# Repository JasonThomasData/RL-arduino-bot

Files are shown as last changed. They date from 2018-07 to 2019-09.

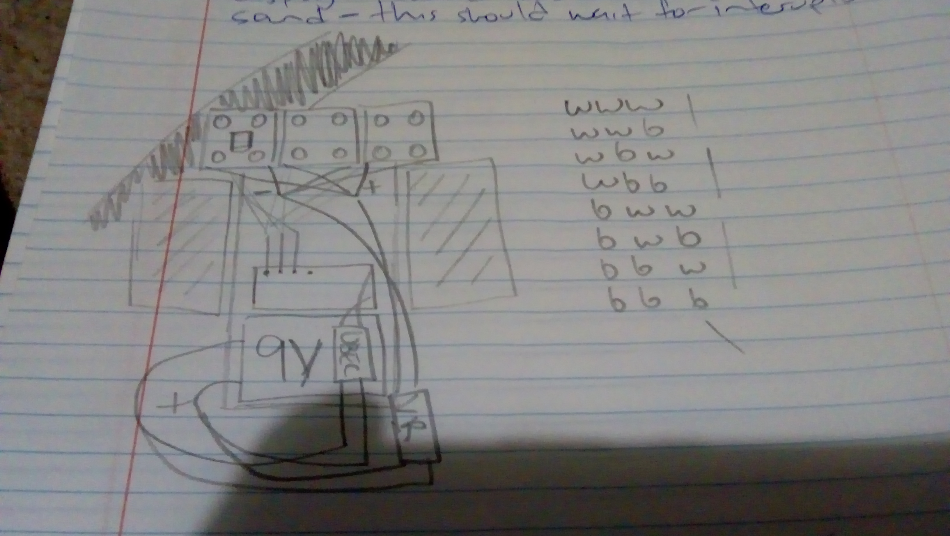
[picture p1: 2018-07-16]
pics/idea1.jpg

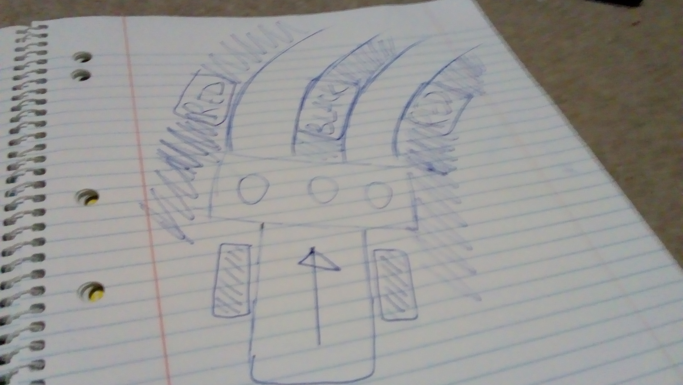
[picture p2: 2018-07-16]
pics/idea2.jpg

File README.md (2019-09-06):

### Requirements

You should download the Arduino IDE to compile the src to your board.

This project uses an Arduino Nano ATMega168 board, or clone. Much of the work on this project was completed using a Mac computer, and if you're using a clone, you will need to [download drivers](https://github.com/adrianmihalko/ch340g-ch34g-ch34x-mac-os-x-driver).

If using a Debian box of some kind, don't use apt to install the Arduino IDE, as [this](https://playground.arduino.cc/Linux/Debian) site warns. Download the binary from their site.

The LinkedList project is in the Sketch, because it is not standard and this is more reliable than Arduino package manager (not sure if it is or not). 

### Tests

```
g++ -std=c++14 tests.cpp -o tests && ./tests
```

### Designs

These parts in `3d_designs/reused_parts/` were incorporated from other projects:

    main_wheel.stl -> https://github.com/davidhrbaty/ArduBot
    small_wheel.stl -> https://github.com/davidhrbaty/ArduBot
    small_wheel_holder.stl -> https://github.com/davidhrbaty/ArduBot
    SG90-A5.stl -> https://www.thingiverse.com/thing:2282898

### Docs

There are a bunch of ideas I drew down in pics/

The control flow diagram was created [here](https://www.draw.io/) and the .xml file is what that app takes for upload. 

### Paths

The paths for the robot to move along are in pics/paths/

These are roughly sized to be printed on A4, but you might need to scale it up slightly.

### Reading

Naming things is hard, so I've reused common names for components by reading [this](http://www-anw.cs.umass.edu/rlr/terms.html).

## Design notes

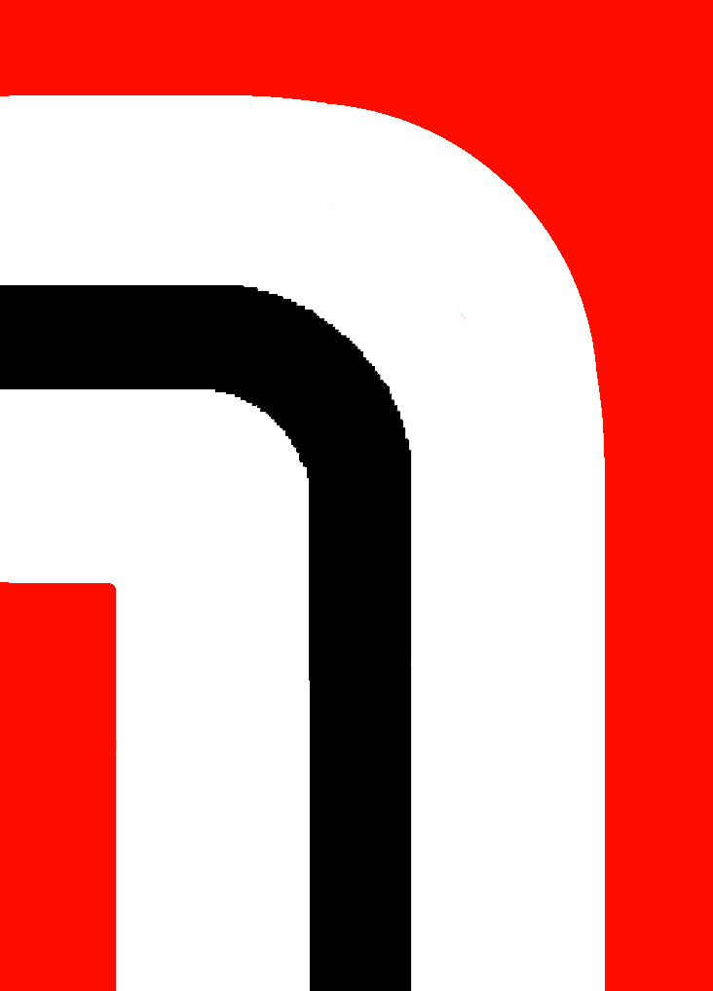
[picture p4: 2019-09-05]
pics/path/turn01.png

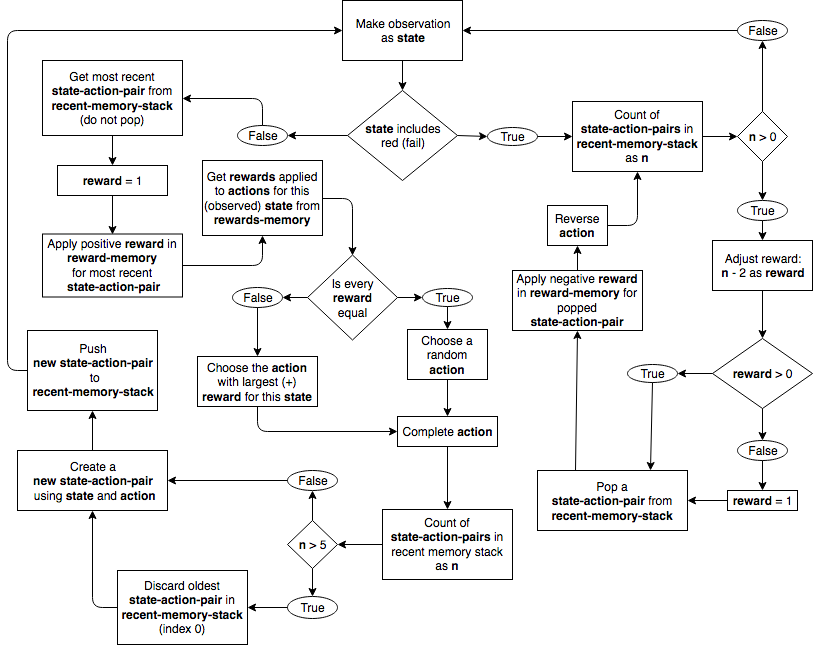
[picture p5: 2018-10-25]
pics/ControlFlow_RL-learning-bot.png

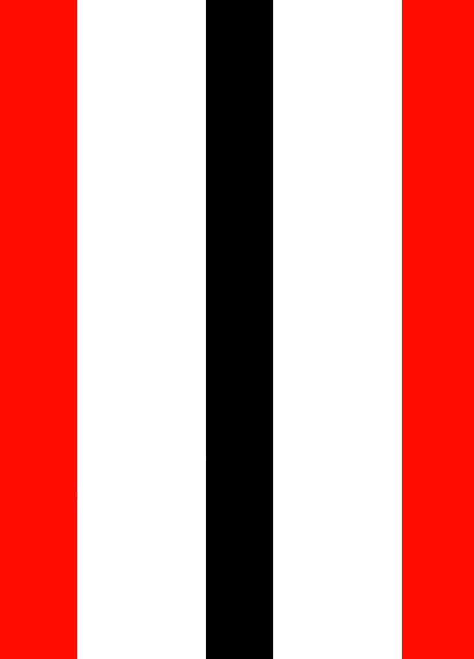
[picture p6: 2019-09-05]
pics/path/straight.png

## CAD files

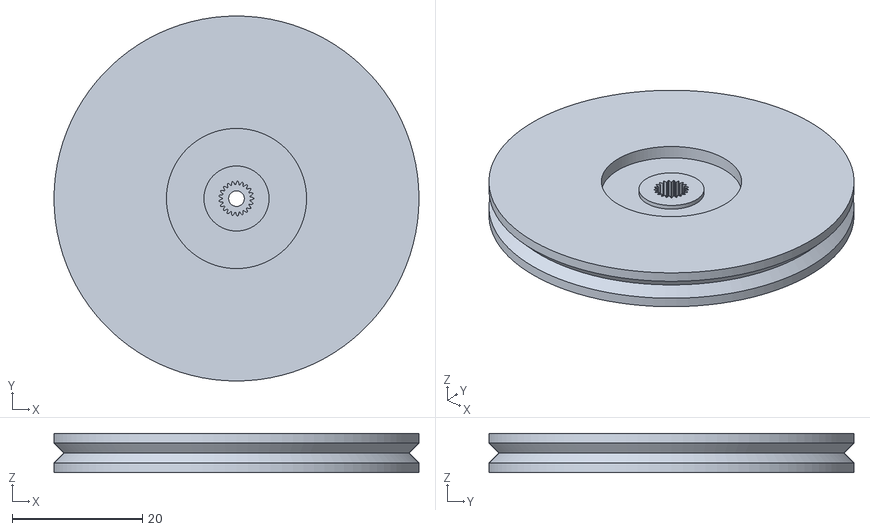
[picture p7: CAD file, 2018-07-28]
3d_designs/main_wheel/main_wheel_with_horn.stl
56.0 x 56.0 x 6.00

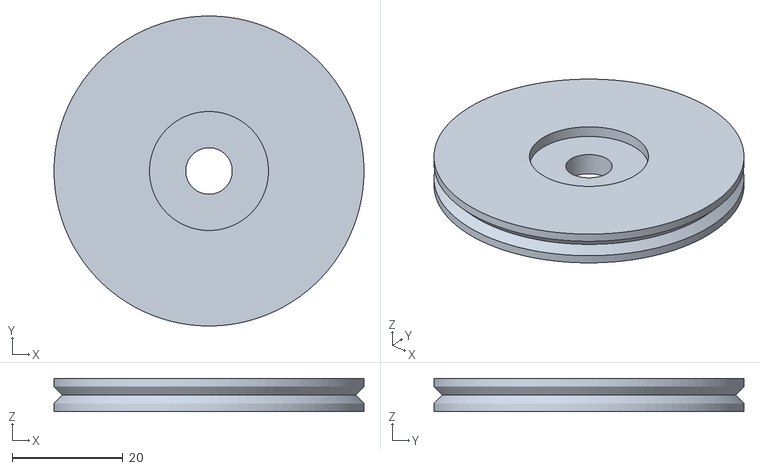
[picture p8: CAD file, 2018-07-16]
3d_designs/reused_parts/main_wheel.stl
56.0 x 56.0 x 6.00

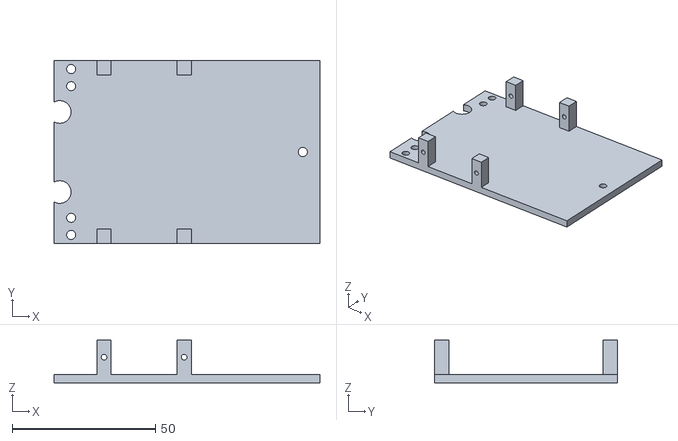
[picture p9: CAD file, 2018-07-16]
3d_designs/chassis/chassis.stl
93.0 x 64.0 x 15.0

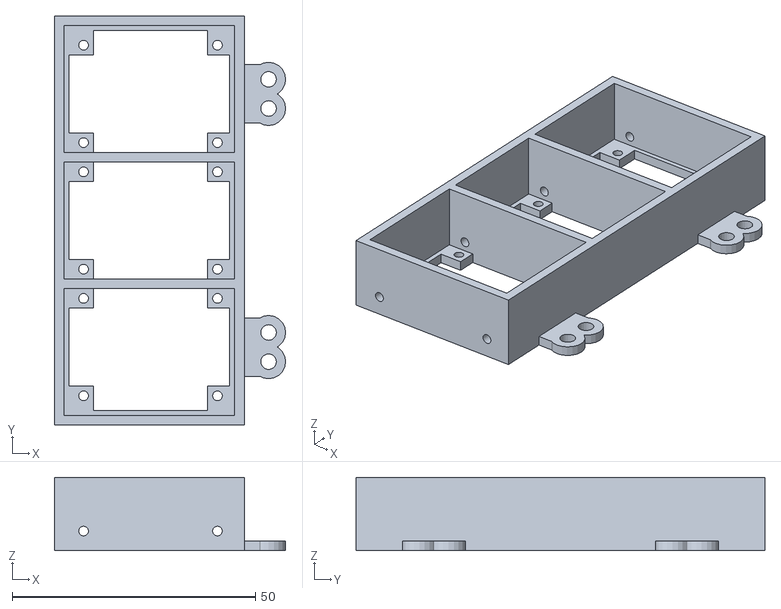
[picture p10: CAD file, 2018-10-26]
3d_designs/sensors/sensors.stl
47.5 x 84.0 x 15.0

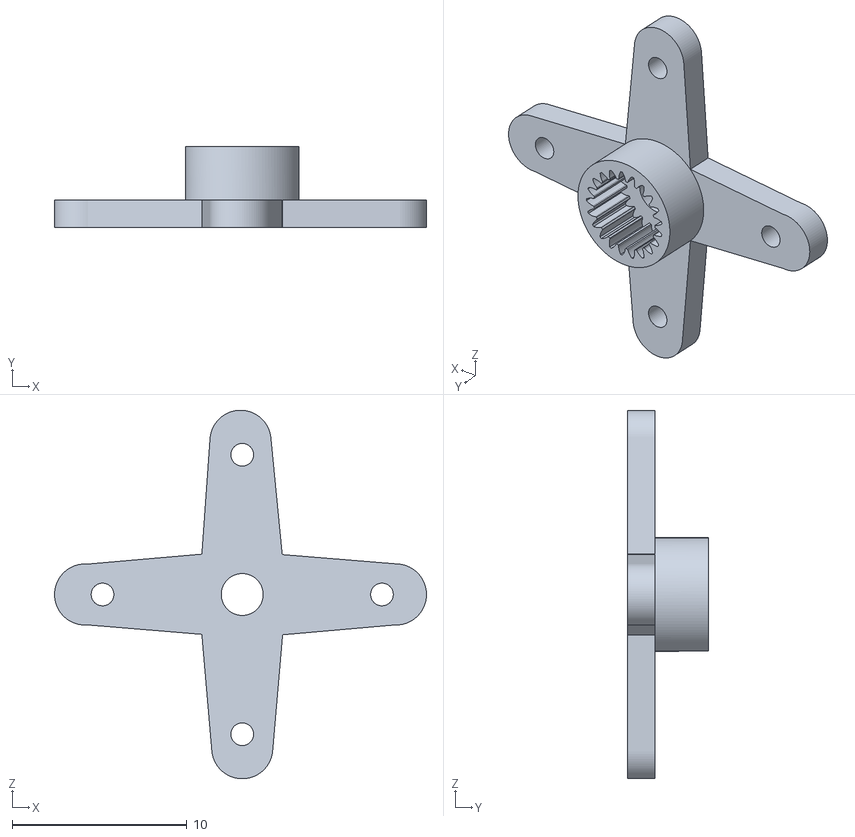
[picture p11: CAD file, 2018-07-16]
3d_designs/reused_parts/SG90-A5.stl
21.3 x 4.66 x 21.1

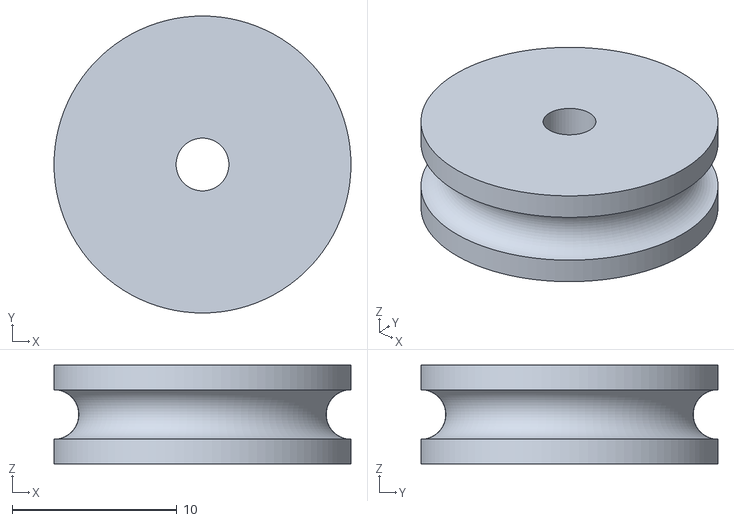
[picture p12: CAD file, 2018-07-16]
3d_designs/reused_parts/small_wheel.stl
18.0 x 18.0 x 6.00

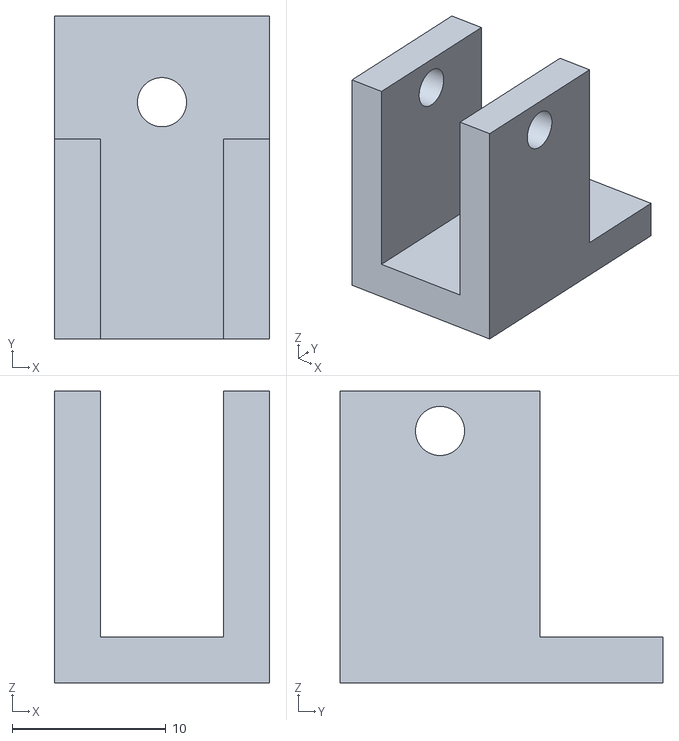
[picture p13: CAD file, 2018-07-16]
3d_designs/reused_parts/small_wheel_holder.stl
14.0 x 21.0 x 19.0

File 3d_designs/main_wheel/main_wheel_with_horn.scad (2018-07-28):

translate([-0.1,10.63,-0.67])
    rotate([90,0,0])
        import("../reused_parts/SG90-A5.stl");

import("../reused_parts/main_wheel.stl");

module wheelHornJoin()
    linear_extrude(height=4.66)
        difference()
        {
            circle(r=5, $fn=50);
            circle(r=3, $fn=20);
        }
 
translate([0,0,-3])
    wheelHornJoin();

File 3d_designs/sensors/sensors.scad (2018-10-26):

use <../common.scad>;

module sensor_holder_block()
    linear_extrude(height=2)
    {
        square([5,5]);
    }
             
module sensor_holder_corner_with_hole(x_offset, y_offset)
    difference()
    {
        sensor_holder_block();
        translate([x_offset,y_offset,0])
            screw_hole(1, 2);
     }

module one_sensor_holder_all_corners()
{
    sensor_holder_corner_with_hole(3, 3); 
    translate([0,21,0])
        sensor_holder_corner_with_hole(3, 2);
    translate([28.5,0,0])
        sensor_holder_corner_with_hole(2, 3);
    translate([28.5,21,0])
        sensor_holder_corner_with_hole(2, 2);
}

module all_sensor_holders()
{
    one_sensor_holder_all_corners();
    translate([0,26,0])
        one_sensor_holder_all_corners();
    translate([0,52,0])
        one_sensor_holder_all_corners();
}

module sensors_mount_outer_brace()
    linear_extrude(height=2)
    {
        square([3,84]);
        translate([36,0,0])
            square([3,84]);
        translate([3,0,0])
            square([33.5,3]);
        translate([3,81,0])
            square([33.5,3]);
    }

module sensors_mount()
{
    sensors_mount_outer_brace();
    translate([3,3,0])
        all_sensor_holders();
}

module sensor_wall(length)
    linear_extrude(height = 15)
    {
        square([length, 2]);
    }

module short_walls()
{
    translate([2,0,0])
        sensor_wall(35);
    translate([2,28,0])
        sensor_wall(35);
    translate([2,54,0])
        sensor_wall(35);
    translate([2,82,0])
        sensor_wall(35);
}

module short_wall_holes()
{
    rotate([-90,0,0])
        translate([6, -4, 0])
            screw_hole(1, 84);
    rotate([-90,0,0])
        translate([33.5, -4, 0])
            screw_hole(1, 84);
}

module long_walls()
{
      translate([2,0,0])
        rotate([0,0,90])
            sensor_wall(84);
    translate([39,0,0])
        rotate([0,0,90])
            sensor_wall(84);
}

module chassis_connector_block()
    linear_extrude(height = 2)
    {
        circle(r=3.5, $fn = 20);
        translate([-5,-3,0])
            square([4, 6]);
    }

module chassis_connector()
    difference()
    {
        chassis_connector_block();
        screw_hole(1.6,2);
    }

module chassis_connectors()
{
    translate([44,10,0])
        chassis_connector();
    translate([44,16,0])
        chassis_connector();
    translate([44,62,0])
        chassis_connector();
    translate([44,68,0])
        chassis_connector();
}

sensors_mount();
difference()
{
    short_walls();
    short_wall_holes();
}
long_walls();
translate([0,3,0])
    chassis_connectors();

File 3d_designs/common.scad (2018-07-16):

module screw_hole(radius, h)
    linear_extrude(height=h)
    {
        circle(r=radius, $fn = 20);
    }

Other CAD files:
3d_designs/chassis/chassis.scad

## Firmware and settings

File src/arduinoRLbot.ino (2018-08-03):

#include <LinkedList.h> // Sketch -> Include Library -> Manage Libraries -> Linked List

/*
 * In this reinforcement learning scenario, the software agent will: 
 *    a) make an observation of the environment state, or of the robot's state in the environment
 *    b) if that state is a fail, and if it is, pop back through list of state-action pairs and give negative rewards. Go back to a)
 *    c) else, give a positive reward for the last state-action pair in list
 *    d) check to see which action has the best reward for the observed state previously
 *    e) complete that action
 *    f) add the state-action pair to the list
 *    REPEAT
 * 
 * It would be preferable to use a HashMap, but, the limitations of an Arduino mean using a fixed length array is more achieveable. However, this means extra care must be paid to naming things, so noone gets confused.
 * Also it would be great to write a minimal unit test suite.
 * 
 * To mitigate against the robot just learning to go backwards and forwards, the robot should detect if it moves a total of zero revs in 10 turns, if so, negative rewards for recorded moves
 * Alternatively, you might use a button to give it a negative reward. 
 */

struct RewardsForActionsAfterObservingAState
{
    int ff; //forward forward
    int fb;
    int bf;
    int bb; //backward backward
};

//Including a hashmap type is too expensive, so this will have to do
//Not sure if a linear search will be performance issue
struct MemoryOfRewardsForStateActionPairs
{
    String key[8];
    RewardsForActionsAfterObservingAState value[8];
};

struct State
{
    char sensorLeft;
    char sensorMiddle;
    char sensorRight;
    char memoryKey[3];
};

struct Action
{
    int leftWheelDirection;
    int rightWheelDirection;
};

struct StateActionPair
{
    State state;
    Action action;
};

struct Sensor
{
    int s0Pin;
    int s1Pin;
    int s2Pin;
    int s3Pin;
    int outputPin;
};

struct ServoInstructions
{
    int signalPin;
    int signalToSet;
};


MemoryOfRewardsForStateActionPairs memoryOfRewardsForStateActionPairs = {
    { "www", "wwb", "wbw", "wbb", "bww", "bwb", "bbw", "bbb" },
    { { 0, 0, 0, 0 }, { 0, 0, 0, 0 }, { 0, 0, 0, 0 }, { 0, 0, 0, 0 }, { 0, 0, 0, 0 }, { 0, 0, 0, 0 }, { 0, 0, 0, 0 }, { 0, 0, 0, 0 } }
};

LinkedList<StateActionPair> mostRecentStateActionPairs = LinkedList<StateActionPair>();

Sensor sensorLeft;
Sensor sensorMiddle;
Sensor sensorRight;

void ConfigureSensor(Sensor *sensor)
{
    pinMode(sensor->s0Pin, OUTPUT);
    pinMode(sensor->s1Pin, OUTPUT);
    pinMode(sensor->s2Pin, OUTPUT);
    pinMode(sensor->s3Pin, OUTPUT);
    pinMode(sensor->outputPin, INPUT);
    digitalWrite(sensor->s0Pin,HIGH);
    digitalWrite(sensor->s1Pin,LOW);
}

void setup()
{   
    sensorLeft = { 1, 2, 3, 4, 13 };
    sensorMiddle = { 5, 6, 7, 8, 14};
    sensorRight = { 9, 10, 11, 12, 15 };
    
    ConfigureSensor(&sensorLeft);
    ConfigureSensor(&sensorMiddle);
    ConfigureSensor(&sensorRight);

    //For debugging
    //Serial.begin(9600);
}

int GetFrequency(Sensor sensor, bool s2_signal, bool s3_signal)
{
    digitalWrite(sensor.s2Pin, s2_signal);
    digitalWrite(sensor.s3Pin, s3_signal);
    return pulseIn(sensor.outputPin, LOW);
}

char CategoriseFrequencyTrio(
    int redFrequency,
    int greenFrequency,
    int blueFrequency)
{
    if (redFrequency < 30,
        greenFrequency < 30,
        blueFrequency < 30)
    {
        return 'b';
    }
    else if (redFrequency < 30,
        greenFrequency > 150,
        blueFrequency > 150)
    {
        return 'r';
    }
    return 'w';
}

char GetColour(Sensor sensor)
{
    int redFrequency = GetFrequency(sensor, false, false); //LOW, LOW
    int greenFrequency = GetFrequency(sensor, true, true); //HIGH, HIGH
    int blueFrequency = GetFrequency(sensor, false, true); //LOW, HIGH
    return CategoriseFrequencyTrio(redFrequency, greenFrequency, blueFrequency);
}

State ObserveState(
    Sensor sensorLeft,
    Sensor sensorMiddle,
    Sensor sensorRight)
{
    State state;
    state.sensorLeft = GetColour(sensorLeft);
    state.sensorMiddle = GetColour(sensorMiddle);
    state.sensorRight = GetColour(sensorRight);

    state.memoryKey[0] = state.sensorLeft;
    state.memoryKey[1] = state.sensorMiddle;
    state.memoryKey[2] = state.sensorRight;

    return state;
}

bool CheckHasObservedRed(State state)
{
    if (state.sensorLeft == 'r' || 
        state.sensorMiddle == 'r' ||
        state.sensorRight == 'r')
    {
        return true;
    }
    return false;
}

RewardsForActionsAfterObservingAState RecallRewardsForActionsAfterObservingAState(State state)
{
    for (int i = 0; i < 8; i++)
    {
        if(memoryOfRewardsForStateActionPairs.key[i] == state.memoryKey)
        {
            return memoryOfRewardsForStateActionPairs.value[i];
        }
    }
}

Action DecideNextAction(RewardsForActionsAfterObservingAState rewardsForActionsAfterObservingAState)
{
    Action nextAction;
    nextAction.leftWheelDirection = 1300; //AntiClockwise
    nextAction.rightWheelDirection = 1700; //Clockwise
    int highestValue = rewardsForActionsAfterObservingAState.ff;

    if (rewardsForActionsAfterObservingAState.fb > highestValue)
    {
        nextAction.leftWheelDirection = 1300; //Clockwise
        nextAction.rightWheelDirection = 1300; //Clockwise
        highestValue = rewardsForActionsAfterObservingAState.fb;
    }
    if (rewardsForActionsAfterObservingAState.bf > highestValue)
    {
        nextAction.leftWheelDirection = 1700; //AntiClockwise
        nextAction.rightWheelDirection = 1700; //AntiClockwise
        highestValue = rewardsForActionsAfterObservingAState.bf;
    }
    if (rewardsForActionsAfterObservingAState.bb > highestValue)
    {
        nextAction.leftWheelDirection = 1700; //Clockwise
        nextAction.rightWheelDirection = 1300; //AntiClockwise
    }
    return nextAction;
}

void ReverseRecentStateActionPairs(LinkedList<StateActionPair> mostRecentStateActionPairs)
{
    while(true)
    {
        if (mostRecentStateActionPairs.size() == 0)
        {
            return;
        }
        StateActionPair recentStateActionPair = mostRecentStateActionPairs.pop();
        //ReverseAction(recentStateActionPair.Action);
        //NegativeRewardForStateActionPair(
    }
}

void loop()
{
    State state = ObserveState(sensorLeft, sensorMiddle, sensorRight);
    bool hasObservedRed = CheckHasObservedRed(state);
    if(hasObservedRed)
    {
        StateActionPair recentStateActionPair = mostRecentStateActionPairs.pop();
        //reverse state-action pairs
        //negative reinforce each of those
        return; //loop() called next moment
    }
    else
    {
        //mark the last move added to the move stack as positive
    }
    RewardsForActionsAfterObservingAState rewardsForActionsAfterObservingAState = RecallRewardsForActionsAfterObservingAState(state);
    Action nextAction = DecideNextAction(rewardsForActionsAfterObservingAState);
    
}

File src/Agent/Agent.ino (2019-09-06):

#include "LinkedList.h"
#include "StateActionPairs.h"
#include "Rewards.h"
#include "Models.h"

MemoryOfRewardsForActions memoryOfRewardsForActions;

LinkedList<StateActionPair> mostRecentStateActionPairs;

SensorModel sensorLeft;
SensorModel sensorMiddle;
SensorModel sensorRight;

ServoModel servoLeft;
ServoModel servoRight;

void setup()
{   
    sensorLeft = { 5, 6, 7 };
    sensorMiddle = { 8, 9, 10 };
    sensorRight = { 11, 12, 13 };

    ConfigureSensor(&sensorLeft);
    ConfigureSensor(&sensorMiddle);
    ConfigureSensor(&sensorRight);

    servoLeft = { 16, 500 };
    servoRight = { 17, 500 };

    mostRecentStateActionPairs = LinkedList<StateActionPair>();

    memoryOfRewardsForActions = {
        { "www", "wwb", "wbw", "wbb", "bww", "bwb", "bbw", "bbb" },
        { { 0, 0, 0, 0 }, { 0, 0, 0, 0 }, { 0, 0, 0, 0 }, { 0, 0, 0, 0 }, { 0, 0, 0, 0 }, { 0, 0, 0, 0 }, { 0, 0, 0, 0 }, { 0, 0, 0, 0 } }
    };

    //For debugging
    //Serial.begin(9600);
}

void loop()
{
    State state = ObserveState(&sensorLeft, &sensorMiddle, &sensorRight);
    bool hasObservedRed = CheckHasObservedRed(state);

    if(hasObservedRed)
    {
        FailStatePolicy(&mostRecentStateActionPairs, &memoryOfRewardsForActions, servoLeft, servoRight);
    }
    else
    {
        StandardPolicy(state, &mostRecentStateActionPairs, &memoryOfRewardsForActions, servoLeft, servoRight);
    }
}

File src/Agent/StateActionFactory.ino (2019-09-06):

#include "StateActionPairs.h"

State CreateState(
    char sensorLeft,
    char sensorMiddle,
    char sensorRight)
{
    State state;
    state.sensorLeft = sensorLeft;
    state.sensorMiddle = sensorMiddle;
    state.sensorRight = sensorRight;

    state.memoryKey[0] = sensorLeft;
    state.memoryKey[1] = sensorMiddle;
    state.memoryKey[2] = sensorRight;
    return state;
}

Action _CreateAction(
    int leftWheelDirection,
    int rightWheelDirection,
    char leftWheelKey,
    char rightWheelKey
    )
{
    Action action;
    action.leftWheelDirection = leftWheelDirection;
    action.rightWheelDirection = rightWheelDirection;
    action.memoryKey[0] = leftWheelKey;
    action.memoryKey[1] = rightWheelKey;
    return action;
}

Action CreateAction_Forward()
{
    Action action = _CreateAction(
        1300, //AntiClockwise
        1700, //Clockwise
        'f',
        'f');
    return action;
}

Action CreateAction_TurnLeft()
{
    Action action = _CreateAction(1700, 1700, 'b', 'f');
    return action;
}

Action CreateAction_TurnRight()
{
    Action action = _CreateAction(1300, 1300, 'f', 'b');
    return action;
}

Action CreateAction_Backward()
{
    Action action = _CreateAction(1700, 1300, 'b', 'b');
    return action;
}

int _ReverseDirection(int originalDirection)
{
    if (originalDirection == 1300)
    {
        return 1700;
    }
    if (originalDirection == 1700)
    {
        return 1300;
    }
    return originalDirection;
}

Action CreateReversedAction(Action originalAction)
{
    Action reversedAction;
    reversedAction.leftWheelDirection = _ReverseDirection(originalAction.leftWheelDirection);
    reversedAction.rightWheelDirection = _ReverseDirection(originalAction.rightWheelDirection);
    return reversedAction;
}

StateActionPair CreateStateActionPair(
    State state,
    Action action)
{
    StateActionPair stateActionPair = { state, action };
    return stateActionPair;
}

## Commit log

2018-07-16 Initial files I've designed for the bot, untested and not printed
    [chassis.scad, chassis.stl, common.scad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]
2018-07-16 Adding attribution for these parts I'm using because that's proper
    [SG90-A5.stl, main_wheel.stl, small_wheel.stl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]
2018-07-16 This wheel is basically two other parts I found stuck together
    [main_wheel_with_horn.scad, main_wheel_with_horn.stl]
2018-07-28 Making join between wheel and horn stronger, fewer surfaces
    [main_wheel_with_horn.scad, main_wheel_with_horn.stl]
2018-07-28 Had wrong file path, updating
    [main_wheel_with_horn.scad]
2018-08-06 Moving file to correct location, needs to be in folder.
    [arduinoRLbot.ino]
2018-08-06 POC for continuous servo
2018-08-06 src contained POC code for some reason, no longer
    [arduinoRLbot.ino]
2018-08-07 Remvoing multiple files until I can resolve issues with type dependencies
    [arduinoRLbot.ino]
2018-08-07 Initial tests revealed some issues
    [arduinoRLbot.ino, tests.cpp]
2018-08-07 Rather than the ugly tests currently, would be great to use function pointers as callbacks
2018-08-10 New methods for dealing with reverse logic
    [Policy.ino]
2018-08-10 Adding some IO servo logic
2018-08-10 Tests to cover reverse logic
    [tests.cpp]
2018-08-28 Actions will now have effects on wheels (servo drivers)
2018-09-23 gcc doesn't have this by default, while clang does
    [tests.cpp]
2018-09-23 Arduino docs say... don't use apt install. I should read docs more often.
2018-10-25 Made some diagrams to illustrate RL concept and policy flow
2018-10-26 Perimeter walls, too much light interferance from outside
    [sensors.scad, sensors.stl]
2019-09-05 Refining this, the latest sensor mount design works
2019-09-05 Useful resource for how the board works
2019-09-06 Fixing tests, removing comments, refactoring
    [Policy.ino, tests.cpp]
